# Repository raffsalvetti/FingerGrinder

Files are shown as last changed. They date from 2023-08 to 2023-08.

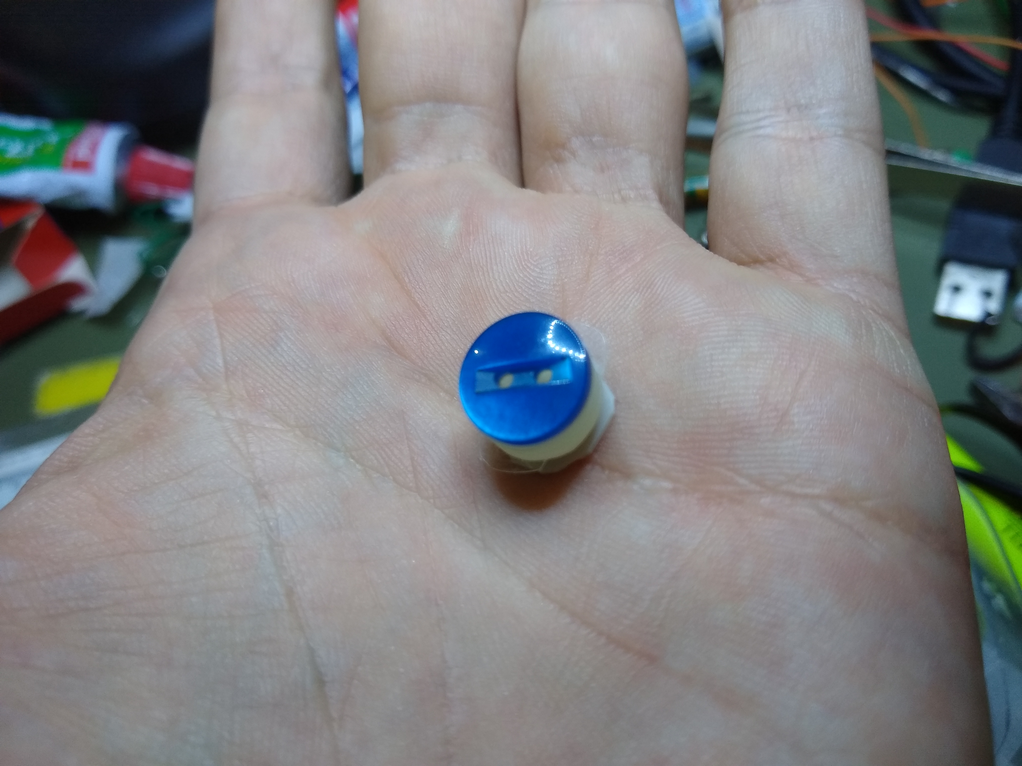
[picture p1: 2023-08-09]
pictures/2020-07-19 19.24.39.jpg

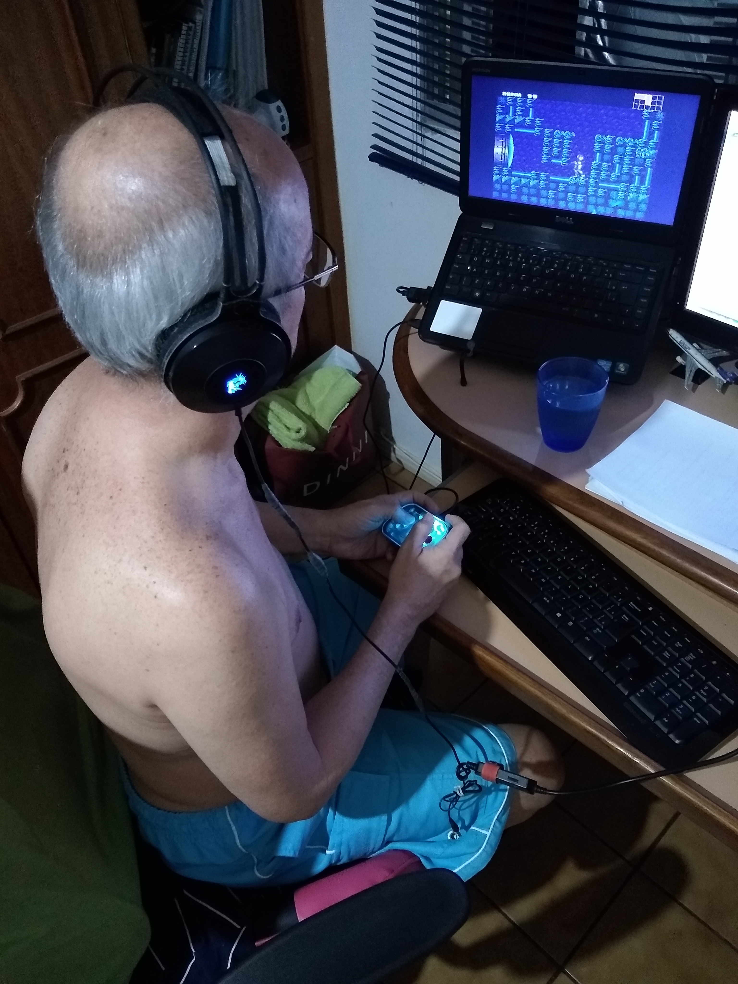
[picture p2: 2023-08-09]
pictures/2020-07-29 21.15.51.jpg

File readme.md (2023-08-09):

# FingerGrinder Gamepad

FingerGrinder is a gamepad project build using the Atmel ATtiny85 microcontroller, shift registers, some passive components and firmware based on the V-USB library.  
Find details about this build here: https://raffsalvetti.dev/2023/07/attiny85-gamepad/
You can find more about the V-USB library at: https://www.obdev.at/vusb/

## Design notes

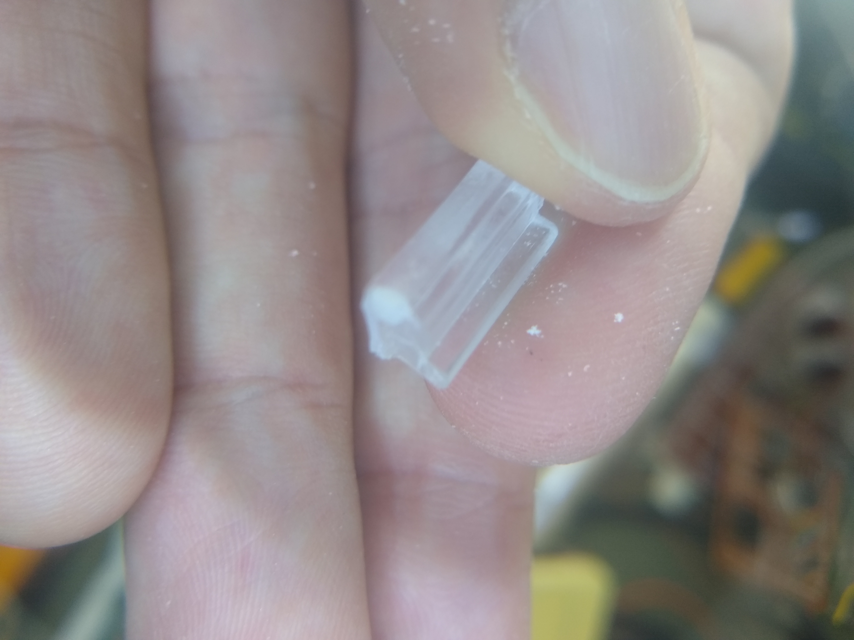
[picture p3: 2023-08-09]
pictures/2020-07-25 12.28.48.jpg

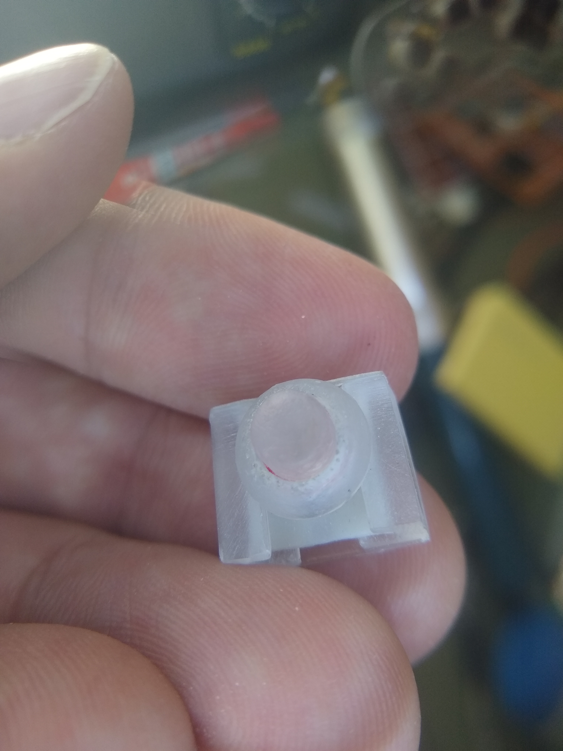
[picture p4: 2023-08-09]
pictures/2020-07-25 12.27.07.jpg

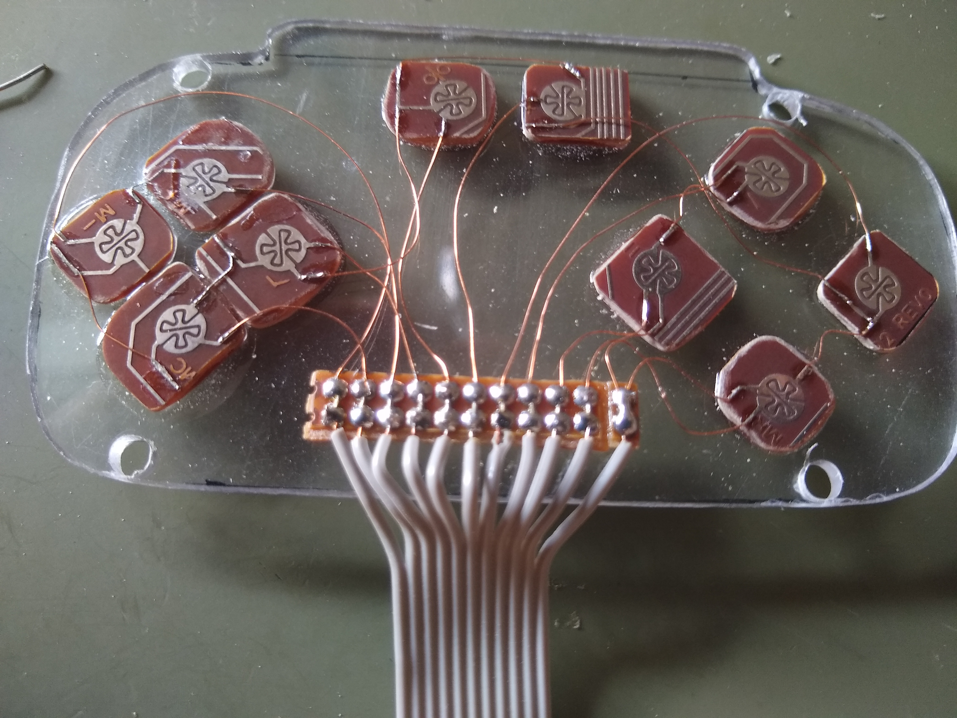
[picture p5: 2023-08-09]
pictures/2020-07-24 15.06.09.jpg

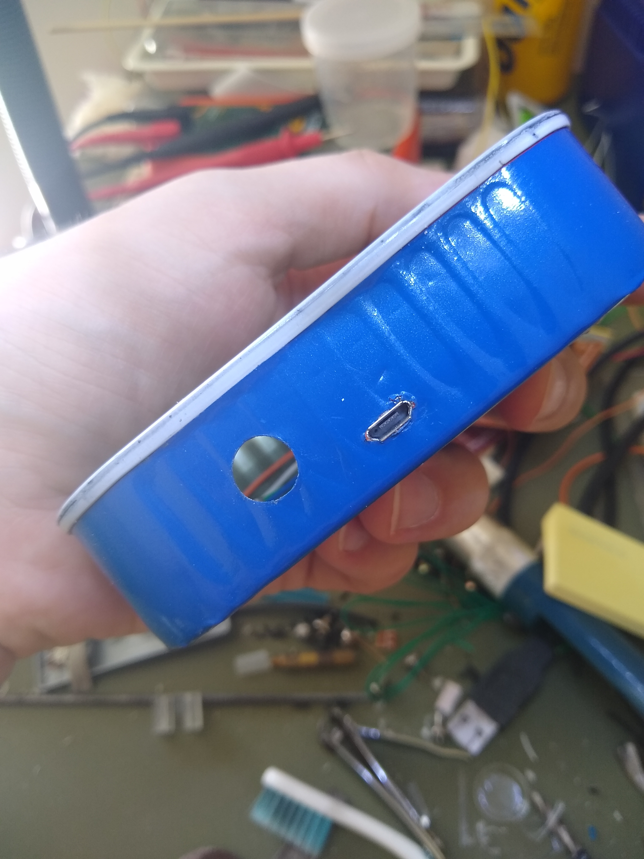
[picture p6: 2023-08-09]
pictures/2020-07-25 12.29.48.jpg

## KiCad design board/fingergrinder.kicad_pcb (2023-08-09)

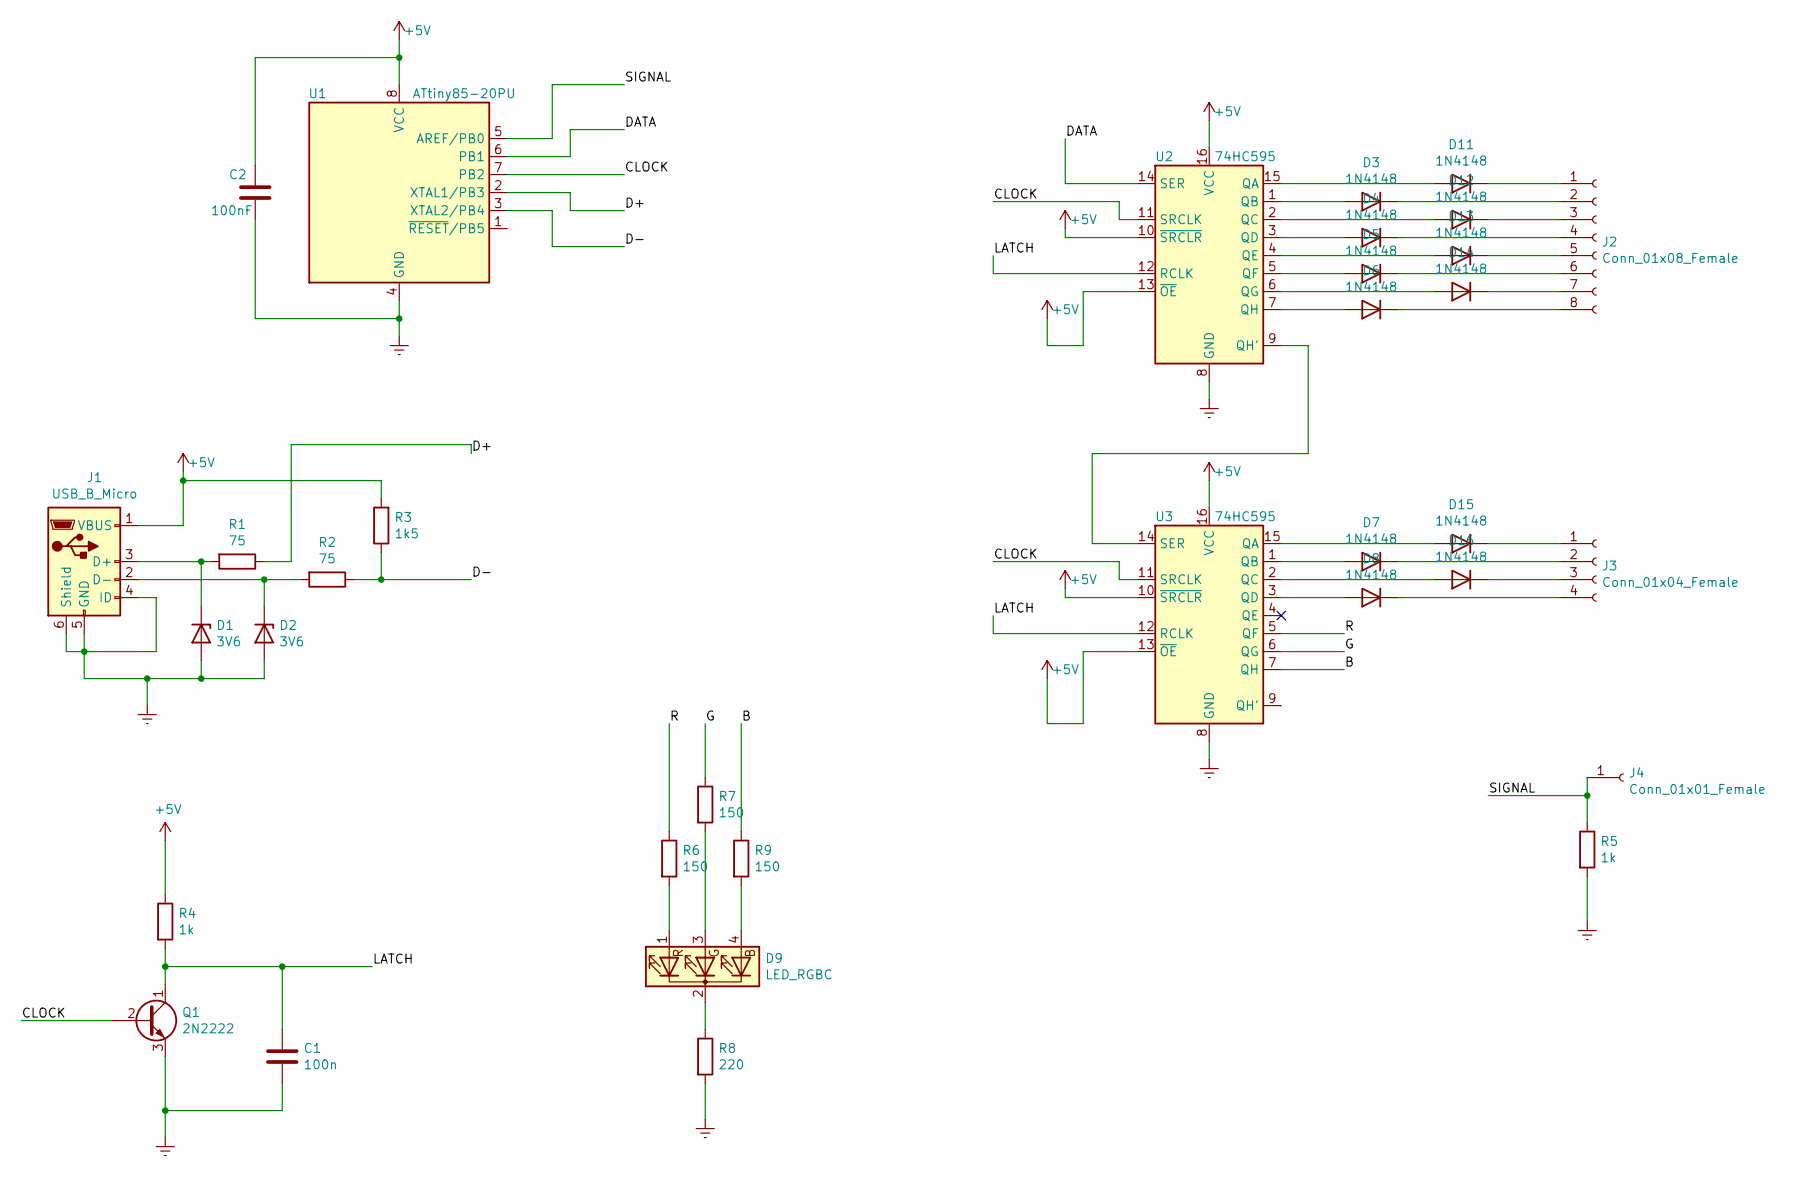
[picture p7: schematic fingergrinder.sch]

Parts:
C1: 100n; C_Disc_D4.7mm_W2.5mm_P5.00mm
C2: 100nF; C_Disc_D4.7mm_W2.5mm_P5.00mm
D1, D2: 3V6; D_DO-35_SOD27_P2.54mm_Vertical_AnodeUp
D3, D4, D5, D6, D7, D8, D11, D12, D13, D14, D15, D16: 1N4148; D_DO-35_SOD27_P7.62mm_Horizontal
D9: LED_RGBC; LED_D5.0mm-4_RGB_Wide_Pins
J1: USB_B_Micro; PinHeader_1x06_P2.54mm_Vertical
J2: Conn_01x08_Female; PinHeader_1x08_P2.54mm_Vertical
J3: Conn_01x04_Female; PinHeader_1x04_P2.54mm_Vertical
J4: Conn_01x01_Female; PinHeader_1x01_P2.54mm_Vertical
Q1: 2N2222; TO-92_Inline_Wide
R1, R2: 75; R_Axial_DIN0207_L6.3mm_D2.5mm_P2.54mm_Vertical
R3: 1k5; R_Axial_DIN0207_L6.3mm_D2.5mm_P2.54mm_Vertical
R4, R5: 1k; R_Axial_DIN0207_L6.3mm_D2.5mm_P2.54mm_Vertical
R6, R7, R9: 150; R_Axial_DIN0207_L6.3mm_D2.5mm_P2.54mm_Vertical
R8: 220; R_Axial_DIN0207_L6.3mm_D2.5mm_P2.54mm_Vertical
U1: ATtiny85-20PU; DIP-8_W7.62mm
U2, U3: 74HC595; DIP-16_W7.62mm

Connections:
+5V: C2.1, J1.1 (VBUS), R3.2, R4.1, U1.8 (VCC), U2.10 (~SRCLR), U2.13 (~OE), U2.16 (VCC), U3.10 (~SRCLR), U3.13 (~OE), U3.16 (VCC)
/B: R9.1, U3.7 (QH)
/CLOCK: Q1.2 (B), U1.7 (PB2), U2.11 (SRCLK), U3.11 (SRCLK)
/D+: R1.1, U1.2 (XTAL1/PB3)
/D-: R2.1, R3.1, U1.3 (XTAL2/PB4)
/DATA: U1.6 (PB1), U2.14 (SER)
/G: R7.1, U3.6 (QG)
/LATCH: C1.1, Q1.1 (C), R4.2, U2.12 (RCLK), U3.12 (RCLK)
/R: R6.1, U3.5 (QF)
/SIGNAL: J4.1, R5.1, U1.5 (AREF/PB0)
Earth: C1.2, C2.2, D1.2 (A), D2.2 (A), J1.4 (ID), J1.5 (GND), J1.6 (Shield), Q1.3 (E), R5.2, R8.2, U1.4 (GND), U2.8 (GND), U3.8 (GND)
unnamed: D1.1 (K), J1.3 (D+), R1.2
unnamed: D2.1 (K), J1.2 (D-), R2.2
unnamed: D3.1 (K), J2.2
unnamed: D3.2 (A), U2.1 (QB)
unnamed: D4.1 (K), J2.4
unnamed: D4.2 (A), U2.3 (QD)
unnamed: D5.1 (K), J2.6
unnamed: D5.2 (A), U2.5 (QF)
unnamed: D6.1 (K), J2.8
unnamed: D6.2 (A), U2.7 (QH)
unnamed: D7.1 (K), J3.2
unnamed: D7.2 (A), U3.1 (QB)
unnamed: D8.1 (K), J3.4
unnamed: D8.2 (A), U3.3 (QD)
unnamed: D9.1 (RA), R6.2
unnamed: D9.2 (K), R8.1
unnamed: D9.3 (GA), R7.2
unnamed: D9.4 (BA), R9.2
unnamed: D11.1 (K), J2.1
unnamed: D11.2 (A), U2.15 (QA)
unnamed: D12.1 (K), J2.3
unnamed: D12.2 (A), U2.2 (QC)
unnamed: D13.1 (K), J2.5
unnamed: D13.2 (A), U2.4 (QE)
unnamed: D14.1 (K), J2.7
unnamed: D14.2 (A), U2.6 (QG)
unnamed: D15.1 (K), J3.1
unnamed: D15.2 (A), U3.15 (QA)
unnamed: D16.1 (K), J3.3
unnamed: D16.2 (A), U3.2 (QC)
unnamed: U2.9 (QH'), U3.14 (SER)

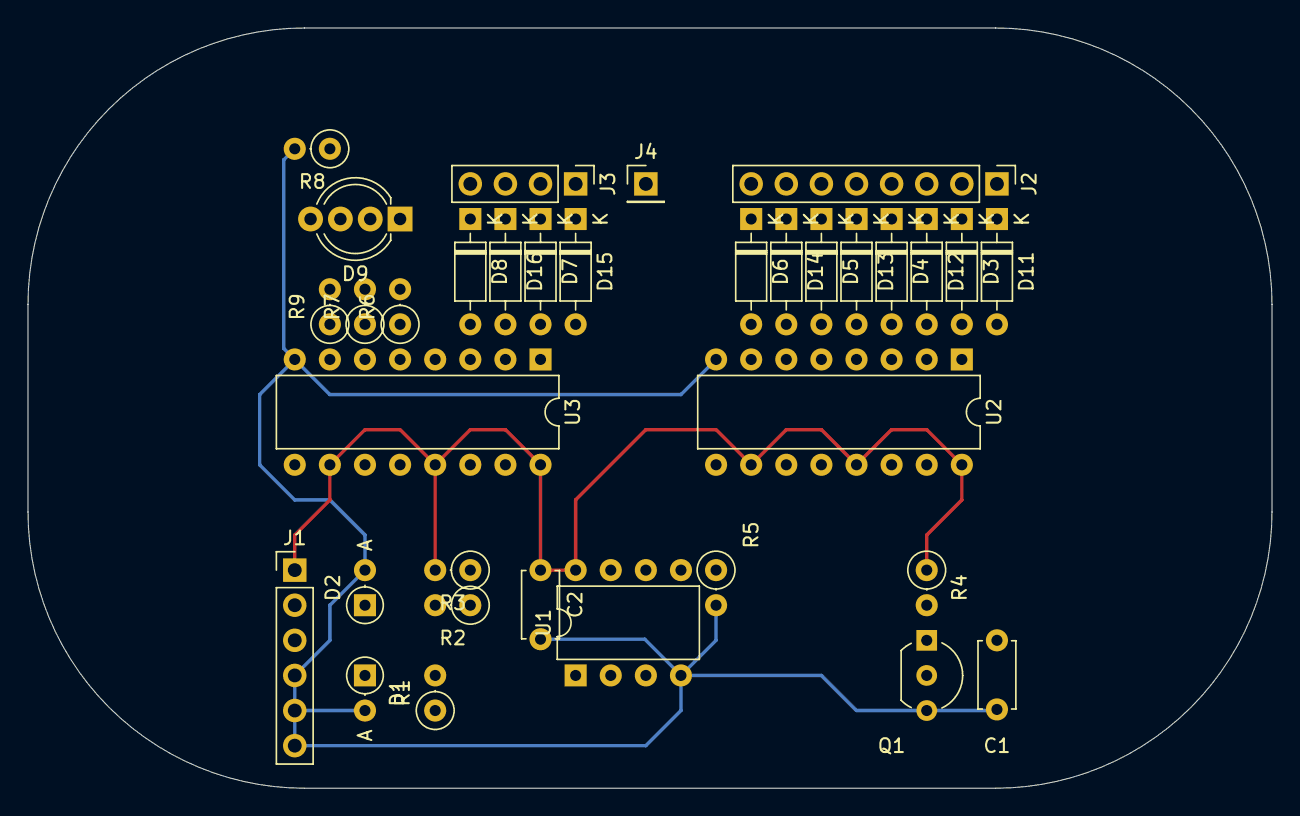
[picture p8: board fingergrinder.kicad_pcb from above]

Board: 2 copper layers, 90.0 x 55.0 mm, 34 parts (0 on the bottom side), 42 nets.

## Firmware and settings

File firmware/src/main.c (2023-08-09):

/*
 * main.c
 *
 *  Created on: 10 de mai de 2020
 *      Author: raffaello
 */
#include <avr/io.h>
#include <avr/wdt.h>
#include <avr/eeprom.h>
#include <avr/interrupt.h>
#include <avr/pgmspace.h>
#include <util/delay.h>
#include "usbdrv/usbdrv.h"
#include "simple_spi.h"
#include "rgb_led_driver.h"

/*
 * ATTINY85 @ 16MHz
 * */

/* USB report descriptor, size must match usbconfig.h USB_CFG_HID_REPORT_DESCRIPTOR_LENGTH */
PROGMEM const char usbHidReportDescriptor[USB_CFG_HID_REPORT_DESCRIPTOR_LENGTH] = {
	0x05, 0x01,                    // USAGE_PAGE (Generic Desktop)
	0x09, 0x05,                    // USAGE (Game Pad)
	0xa1, 0x01,                    // COLLECTION (Application)
	0x09, 0x01,                    //   USAGE (Pointer)
	0xa1, 0x00,                    //   COLLECTION (Physical)
	0x09, 0x30,                    //     USAGE (X)
	0x09, 0x31,                    //     USAGE (Y)
	0x15, 0x00,                    //   LOGICAL_MINIMUM (0)
	0x26, 0xff, 0x00,              //   LOGICAL_MAXIMUM (255)
	0x75, 0x08,                    //   REPORT_SIZE (8)
	0x95, 0x02,                    //   REPORT_COUNT (2)
	0x81, 0x02,                    //   INPUT (Data, Var, Abs)
	0xc0,                          // END_COLLECTION
	0x05, 0x09,                    // USAGE_PAGE (Button)
	0x19, 0x01,                    //   USAGE_MINIMUM (Button 1)
	0x29, 0x08,                    //   USAGE_MAXIMUM (Button 8)
	0x15, 0x00,                    //   LOGICAL_MINIMUM (0)
	0x25, 0x01,                    //   LOGICAL_MAXIMUM (1)
	0x75, 0x01,                    // REPORT_SIZE (1)
	0x95, 0x08,                    // REPORT_COUNT (8)
	0x81, 0x02,                    // INPUT (Data, Var, Abs)
	0xc0                           // END_COLLECTION
};

static uchar report_buffer[3] = {0x80, 0x80, 0x00}; //initial positions
static uchar idleRate;   /* repeat rate for keyboards, never used for mice */
static volatile uint16_t last_signal = 0x0000;
static volatile uchar timer_trigger_counter = 0;
static volatile uchar has_changed = 0;

static void buildReport() {
	uchar directions = (uchar) (0x000f & last_signal);
	report_buffer[0] = 0x80; 										//center x
	report_buffer[1] = 0x80; 										//center y
	report_buffer[2] = (uchar) ((0x0ff0 & last_signal) >> 4); 		// buttons
	if(directions & 0x04) { report_buffer[1] = 0x00; }				// up
	if(directions & 0x08) { report_buffer[0] = 0xff; }				// right
	if(directions & 0x02) { report_buffer[1] = 0xff; }				// down
	if(directions & 0x01) { report_buffer[0] = 0x00; }				// left
}

usbMsgLen_t usbFunctionSetup(uchar data[8]) {
	usbRequest_t    *rq = (void *)data;

    /* The following requests are never used. But since they are required by
     * the specification, we implement them in this example.
     */
    if((rq->bmRequestType & USBRQ_TYPE_MASK) == USBRQ_TYPE_CLASS){    /* class request type */
        if(rq->bRequest == USBRQ_HID_GET_REPORT){  /* wValue: ReportType (highbyte), ReportID (lowbyte) */
            /* we only have one report type, so don't look at wValue */
            usbMsgPtr = (void *)&report_buffer;
            return sizeof(report_buffer);
        }else if(rq->bRequest == USBRQ_HID_GET_IDLE){
            usbMsgPtr = &idleRate;
            return 1;
        }else if(rq->bRequest == USBRQ_HID_SET_IDLE){
            idleRate = rq->wValue.bytes[1];
        }
    }else{
        /* no vendor specific requests implemented */
    }
    return 0;   /* default for not implemented requests: return no data back to host */
}

void configure_hardware() {
	simple_spi_init();
	SPI_PORT &= ~(1 << DI_PIN); //pull down

	//reset both shift registers
	simple_spi_send(0x00); //reset button scanner
	simple_spi_send(0x00); //reset button scanner
}

int main(void) {
	uint16_t mask = 0x0001;
	uint16_t signal = 0x0000;
	uchar   b1, b2;
	configure_hardware();
	rgb_led_init();

	usbDeviceDisconnect();
	for(b1 = 0 ; b1 < 20 ; b1++) {  /* 300 ms disconnect */
		_delay_ms(15);
	}
	usbDeviceConnect();
	wdt_enable(WDTO_1S);
	usbInit();
	sei();

	has_changed = 1; //build the first report

	for(;;) {
		wdt_reset();
		usbPoll();
		if(usbInterruptIsReady()) { //send data when the usb is ready to receive
			if(has_changed) { //and when any change occurred
				buildReport(); //build the report according descriptor
				has_changed = 0; //clean change flag
			}
			usbSetInterrupt(report_buffer, sizeof(report_buffer)); //send
		}

		while(!(mask & 0x1000)) {
			// placing bit on right place to shift into shifters
			b2 = (uchar)((mask & 0xff00) >> 8);
			b1 = (uchar)(mask & 0x00ff);

			b2 |= (rgb_led_state() << 5); //next rgb led state

			/*
			 * the folowing 3 lines are needed to activate the clock line
			 * the pin should be pulled up for at least 1us
			 * this will charge the 100nf capacitor and it will activate the transistor
			 * this time was selected by trial and error and it is dependent of the circuit conditions
			 * */
			SPI_PORT |= (1 << USCK_PIN); //enable clock (and charge latch cap)
			_delay_us(1); //waiting for charge
			SPI_PORT &= ~(1 << USCK_PIN); //disable clock

			simple_spi_send(b2);
			simple_spi_send(b1);
			_delay_us(666); //waiting for button settle down (debouncing)

			if(PINB & 0x01) { //reading if the button is pressed
				signal |= mask; //add the state of each button to the buffer
			}
			mask = (mask << 1); //set the next button to be read
		}
		if(last_signal != signal) {
			last_signal = signal;
			has_changed = 1;
		}
		mask = 0x0001; //reset mask state
		signal = 0x0000; //reset signal report state
	}
	return 0;
}

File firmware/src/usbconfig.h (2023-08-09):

/* Name: usbconfig.h
 * Project: V-USB, virtual USB port for Atmel's(r) AVR(r) microcontrollers
 * Author: Christian Starkjohann
 * Creation Date: 2005-04-01
 * Tabsize: 4
 * Copyright: (c) 2005 by OBJECTIVE DEVELOPMENT Software GmbH
 * License: GNU GPL v2 (see License.txt), GNU GPL v3 or proprietary (CommercialLicense.txt)
 */

#ifndef __usbconfig_h_included__
#define __usbconfig_h_included__

/*
General Description:
This file is an example configuration (with inline documentation) for the USB
driver. It configures V-USB for USB D+ connected to Port D bit 2 (which is
also hardware interrupt 0 on many devices) and USB D- to Port D bit 4. You may
wire the lines to any other port, as long as D+ is also wired to INT0 (or any
other hardware interrupt, as long as it is the highest level interrupt, see
section at the end of this file).
+ To create your own usbconfig.h file, copy this file to your project's
+ firmware source directory) and rename it to "usbconfig.h".
+ Then edit it accordingly.
*/

/* ---------------------------- Hardware Config ---------------------------- */

#define USB_CFG_IOPORTNAME      B
/* This is the port where the USB bus is connected. When you configure it to
 * "B", the registers PORTB, PINB and DDRB will be used.
 */
#define USB_CFG_DMINUS_BIT      3
/* This is the bit number in USB_CFG_IOPORT where the USB D- line is connected.
 * This may be any bit in the port.
 */
#define USB_CFG_DPLUS_BIT       4
/* This is the bit number in USB_CFG_IOPORT where the USB D+ line is connected.
 * This may be any bit in the port. Please note that D+ must also be connected
 * to interrupt pin INT0! [You can also use other interrupts, see section
 * "Optional MCU Description" below, or you can connect D- to the interrupt, as
 * it is required if you use the USB_COUNT_SOF feature. If you use D- for the
 * interrupt, the USB interrupt will also be triggered at Start-Of-Frame
 * markers every millisecond.]
 */
#define USB_CFG_CLOCK_KHZ       (F_CPU/1000)
/* Clock rate of the AVR in kHz. Legal values are 12000, 12800, 15000, 16000,
 * 16500, 18000 and 20000. The 12.8 MHz and 16.5 MHz versions of the code
 * require no crystal, they tolerate +/- 1% deviation from the nominal
 * frequency. All other rates require a precision of 2000 ppm and thus a
 * crystal!
 * Since F_CPU should be defined to your actual clock rate anyway, you should
 * not need to modify this setting.
 */

/* ------------- Set up interrupt configuration (CPU specific) --------------   */
/* The register names change quite a bit in the ATtiny family. Pay attention    */
/* to the manual. Note that the interrupt flag system is still used even though */
/* interrupts are disabled. So this has to be configured correctly.             */
// setup interrupt for Pin Change for D+
#define USB_INTR_CFG            PCMSK
#define USB_INTR_CFG_SET        (1 << USB_CFG_DPLUS_BIT)
#define USB_INTR_CFG_CLR        0
#define USB_INTR_ENABLE         GIMSK
#define USB_INTR_ENABLE_BIT     PCIE
#define USB_INTR_PENDING        GIFR
#define USB_INTR_PENDING_BIT    PCIF
#define USB_INTR_VECTOR         PCINT0_vect

#define USB_CFG_CHECK_CRC       0
/* Define this to 1 if you want that the driver checks integrity of incoming
 * data packets (CRC checks). CRC checks cost quite a bit of code size and are
 * currently only available for 18 MHz crystal clock. You must choose
 * USB_CFG_CLOCK_KHZ = 18000 if you enable this option.
 */

/* ----------------------- Optional Hardware Config ------------------------ */

/* #define USB_CFG_PULLUP_IOPORTNAME   D */
/* If you connect the 1.5k pullup resistor from D- to a port pin instead of
 * V+, you can connect and disconnect the device from firmware by calling
 * the macros usbDeviceConnect() and usbDeviceDisconnect() (see usbdrv.h).
 * This constant defines the port on which the pullup resistor is connected.
 */
/* #define USB_CFG_PULLUP_BIT          4 */
/* This constant defines the bit number in USB_CFG_PULLUP_IOPORT (defined
 * above) where the 1.5k pullup resistor is connected. See description
 * above for details.
 */

/* --------------------------- Functional Range ---------------------------- */
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

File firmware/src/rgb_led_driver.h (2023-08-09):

/*
 * rgb_led_driver.h
 *
 *  Created on: 27 de jun de 2020
 *      Author: raffaello
 */

#ifndef RGB_LED_DRIVER_H_
#define RGB_LED_DRIVER_H_

#include <avr/io.h>

/*
 * I got this code from
 * https://blog.podkalicki.com/attiny13-controlling-led-rgb-fancy-light-effects/
 * */

#ifndef LED_RED
#define    LED_RED			0
#endif
#ifndef LED_GREEN
#define    LED_GREEN		1
#endif
#ifndef LED_BLUE
#define    LED_BLUE			2
#endif

#ifndef MAX_STEP
#define    MAX_STEP			(32)
#endif
#ifndef STEP
#define    STEP				(1)
#endif

#define    REDtoYELLOW		(0)
#define    YELLOWtoGREEN	(1)
#define    GREENtoCYAN		(2)
#define    CYANtoBLUE		(3)
#define    BLUEtoVIOLET		(4)
#define    VIOLETtoRED		(5)

void rgb_led_init();
uint8_t rgb_led_state();

#endif /* RGB_LED_DRIVER_H_ */
